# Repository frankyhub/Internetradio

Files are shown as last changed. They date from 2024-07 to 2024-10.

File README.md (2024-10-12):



<div align="center">

|[:skull:ISSUE](https://github.com/frankyhub/Internetradio/issues?q=is%3Aissue)|[:speech_balloon: Forum /Discussion](https://github.com/frankyhub/Internetradio/discussions)|[:grey_question:WiKi](https://github.com/frankyhub/Internetradio/wiki)||
|--|--|--|--|
| | | | |
||<a href="https://github.com/frankyhub/Internetradio/issues">|<a href="https://github.com/frankyhub/Internetradio/discussions">|<a href="https://github.com/frankyhub/Internetradio/releases">|
|| <a href="https://github.com/frankyhub/Internetradio/pulse" alt="Activity">| <a href="https://github.com/frankyhub/Internetradio/graphs/traffic">  |<a href="https://github.com/frankyhub?tab=stars"> |
</div>

# Internetradio
Internetradio mit WEB-Server, OTA-Funktion, TFT 1,88 oder LCD 4 Zeilen Display, digitales Amplifier Board MAX98357A

## Story
Das Internetradio steht mit einem  TFT 1,88" Display oder einem LCD 4x20 Display mit I2C Schnittstelle zur Verfügung.
Neben dem gerade gespielten Sender werden Datum und Uhrzeit, sowie die aktuelle Lautstärke angezeigt. 
In den beiden unteren Zeilen sind die Informationen zum laufenden Programm, die mit dem Audiostream mitgeschickt werden. 
Die Lautstärkeregelung erfolgt ebenso wie die Senderwahl über einen Rotary-Encoder. Die Konfiguration kann
auch über einen Browser erfolgen. Über diesen Weg ist die Senderliste veränder- und erweiterbar. 
Da nicht jede Sender-URL abspielbar ist, kann die URL über die Browserkonfiguration vor dem speichern vorab getestet werden. 

Internetradio 

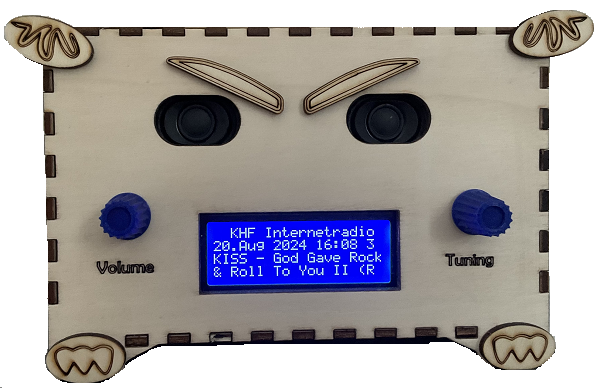
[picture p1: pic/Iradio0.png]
 

---

## Hardware

| Anzahl | Bezeichnung | 
| --- | --- |
| 1  | ESP32vn IoT UNO |
| 1  |  Shield  |
|  2 |  I2S Digitalverstärker mit MAX98357A  |
| 2  |  Lautsprecher  |
| 1  |  Widerstand 470 kOhm  |
| 1  |  Widerstand 10 kOhm  |
| 1  |  Elko 1000uF / 10V  |
| 2  | Drehgeber Encoder  |
| 2  | Drehknöpfe für 6mm Achse |
|  1 | TFT 1,88" |
|  1 | altern. LCD 4x20 |
| 1  | Gehäuse |
|  1 |  5V-Netzteil  |
| | Kabel |
|  --- |  ---  |

---

## Verdrahtung

Mit LCD-Display

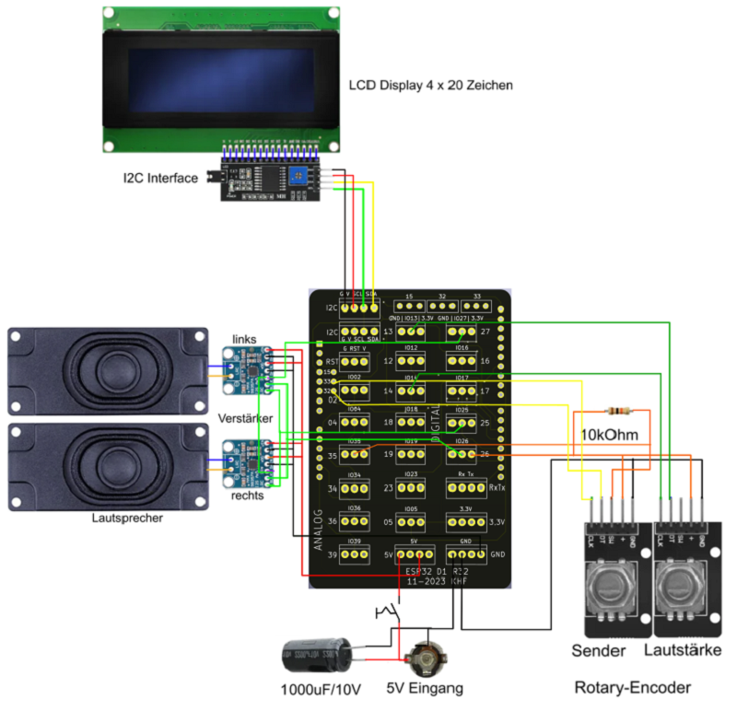
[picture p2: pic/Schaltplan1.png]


Mit TFT-Display

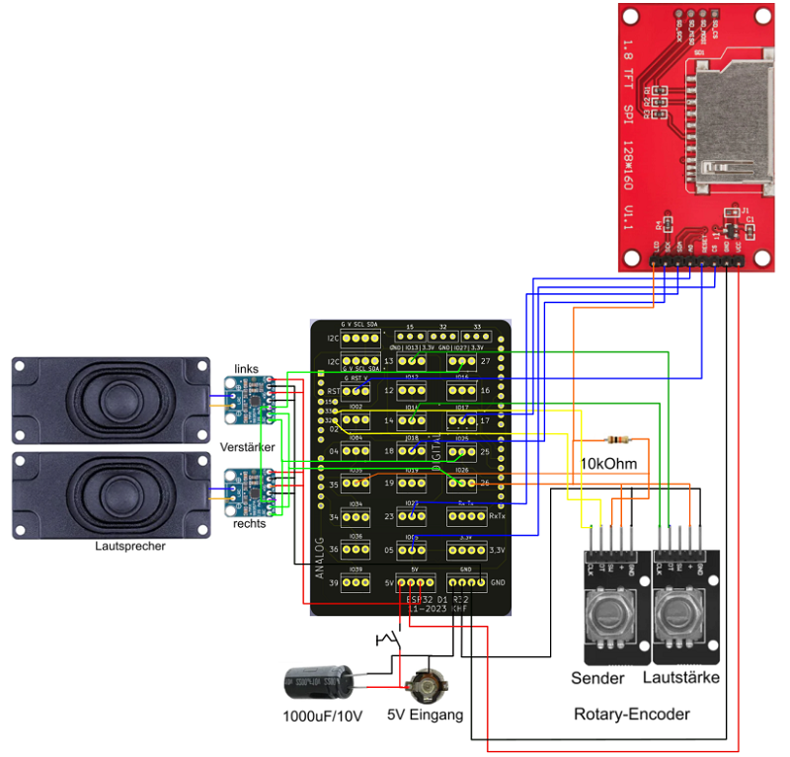
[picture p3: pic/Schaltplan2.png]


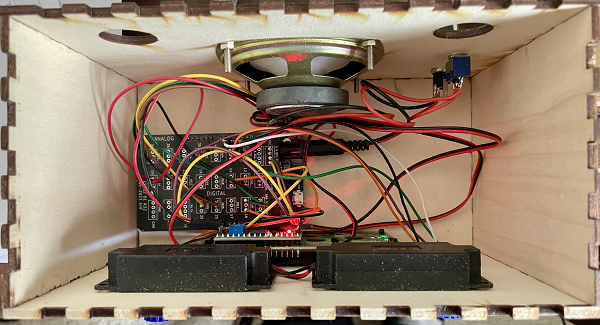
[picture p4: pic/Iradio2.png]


---

### Inbetriebnahme

Bei der ersten Inbetriebnahme ist noch keine SSID und kein WLAN-Passwort vorhanden. Es kann daher keine Verbindung zum lokalen WLAN hergestellt werden. 
Ein Accesspoint mit der SSID „Internetradio“ wird gestartet. Mit einem Smartphone oder einem Tablet kann nun eine Verbindung zu diesem 
Accesspoint hergestellt werden. Danach kann in einem Browser über die Adresse 192.168.4.1 die Konfigurationsseite aufgerufen werden.

Nach dem Neustart sollte die Verbindung zum lokalen WLAN erfolgreich hergestellt werden können. 
Die Wiedergabe der ersten Station aus der Senderliste sollte mit einer Lautstärke von 50% starten. 
Mit dem Encoder für die Lautstärke kann die Verstärkung eingestellt werden. Änderungen werden in den Präferenzen gespeichert, 
sodass beim nächsten Einschalten dieselbe Lautstärke eingestellt wird. Mit dem anderen Encoder kann ein Sender aus der Senderliste gewählt werden. 
Beim Drehen des Encoders wird in der zweiten Zeile des Displays der Name der Station angezeigt. 
Durch Drücken des Kopfes am Encoder wird die gerade angezeigte Station gespeichert und die Wiedergabe gestartet. 
Auch dieser Wert wird in den Präferenzen gespeichert und beim nächsten Start die zuletzt gewählte Station wiedergegeben. 
Wird der Knopf am Encoder innerhalb von 10 Sekunden nicht gedrückt, springt die Anzeige auf die aktuelle Station zurück.

## WLAN-Daten speichern

Aufruf "Internetradio" in den WLAN-Einstellungen

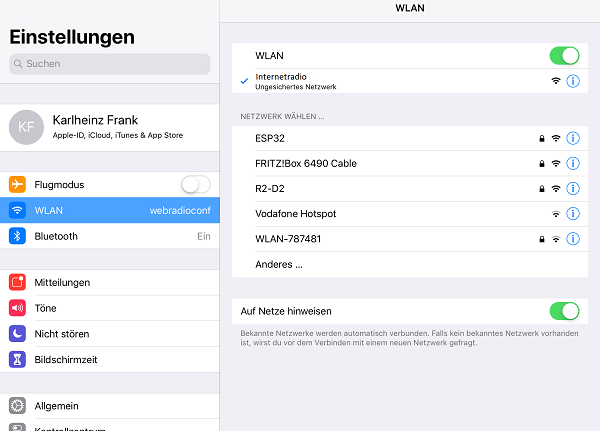
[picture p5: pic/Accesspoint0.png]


Im Browser 192.168.4.1 eingeben

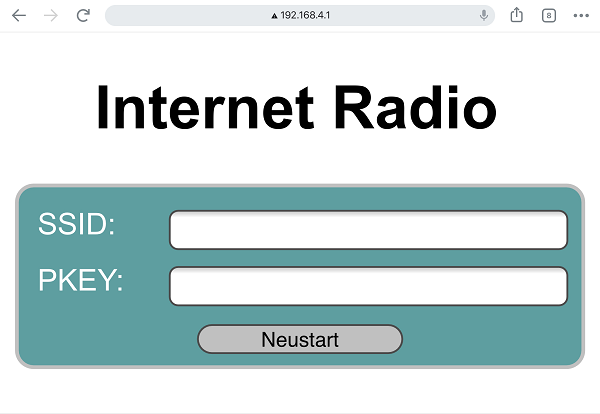
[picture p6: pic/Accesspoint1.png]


Im Browser die Zugangsdaten eingeben und neu starten

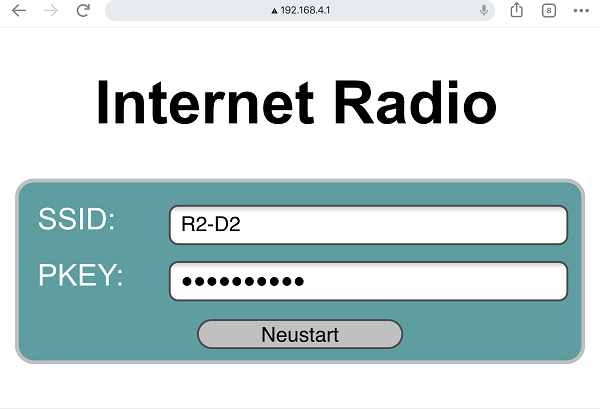
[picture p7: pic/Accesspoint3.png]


Kontrolle mit dem Seriellen Monitor

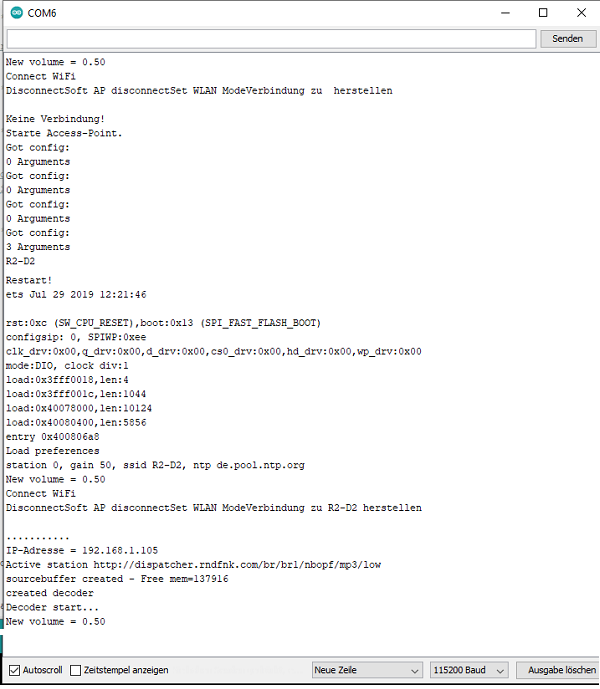
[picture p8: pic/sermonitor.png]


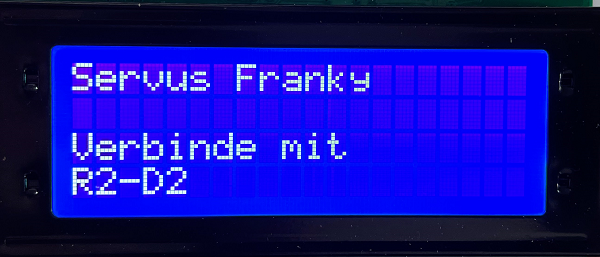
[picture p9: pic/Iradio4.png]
  

---

### Konfigurations Update

Über die URL http://Internetradio/ sollte die Konfigurationsseite abrufbar sein. Im oberen Teil können die Zugangsdaten und der NTP-Server geändert werden. 
Die Änderungen werden erst dann wirksam, wenn der Knopf „Speichern“ geklickt wurde.
Mit dem Knopf „Neustart“ kann ein Neustart ausgelöst werden.

Die Dropdown-Liste enthält alle Sender der Senderliste. Auswählbare Sender haben vor dem Namen einen schwarzen Punkt. 
Im Formular darunter sind die Daten zur ausgewählten Station gelistet und können geändert werden. 
Ist das Häkchen bei „Verwenden“ nicht gesetzt, ist die Station im Gerät nicht wählbar.
Da manche URLs nicht funktionieren, sollte man die neue URL testen (Testen-Button). 
Ein Klicken auf diesen Knopf startet die Wiedergabe der URL am Gerät. 
Sollte die Wiedergabe nicht funktionieren, wird sofort wieder auf den aktuellen Sender zurückgeschaltet und eine Meldung angezeigt. 
Ist die Wiedergabe möglich, wird eine Box mit einem Knopf angezeigt. Ein Klicken auf diesen Knopf schließt die Box und beendet den Test. 
Es wird wieder die aktuelle Station wiedergegeben.  Mit dem Knopf „Ändern“ können die Änderungen für die ausgewählte Station dauerhaft geändert werden.

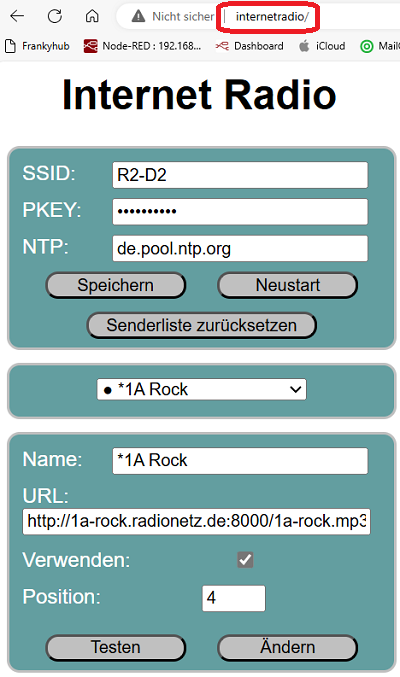
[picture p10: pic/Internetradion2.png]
 

---

 ## Programmierung über OTA

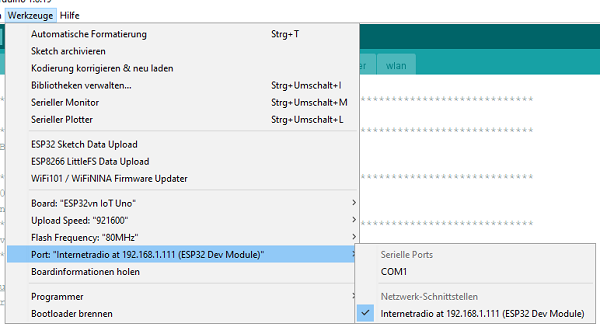
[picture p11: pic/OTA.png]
 

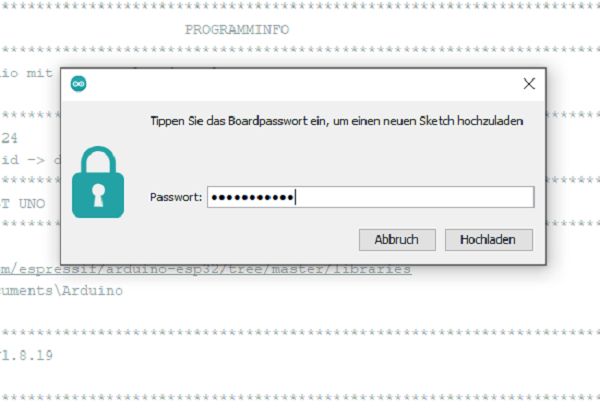
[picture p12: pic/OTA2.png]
 
 
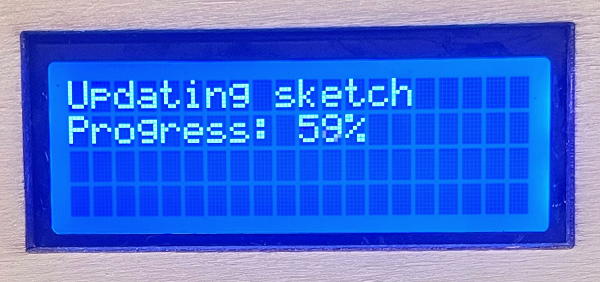
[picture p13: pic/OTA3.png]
  

 ---

## Voreingestellte Senderliste

1* Spitalradio LuZ	https://s10.streamingcloud.online:13552/radioluz320.mp3

2 Bayern1		http://dispatcher.rndfnk.com/br/br1/nbopf/mp3/low

3 Antenne Bayern	http://stream.antenne.de/antenne

4 NRW Rockradio	http://rnrw.cast.addradio.de/rnrw-0182/deinrock/low/stream.mp3

5 RT1 Rock	http://rt1.radio/tu6h1

6* 1A Rock		http://1a-rock.radionetz.de:8000/1a-rock.mp3

7* NDW		http://1a-ndw.radionetz.de/1a-ndw.mp3

8 WDR 2		http://wdr-wdr2-aachenundregion.icecastssl.wdr.de/wdr/wdr2/aachenundregion/mp3/128/stream.mp3

9 WDR3		http://wdr-wdr3-live.icecastssl.wdr.de/wdr/wdr3/live/mp3/128/stream.mp3

10 HR3		http://dispatcher.rndfnk.com/hr/hr3/suedhessen/high

11 MDR		http://mdr-284280-1.cast.mdr.de/mdr/284280/1/mp3/low/stream.mp3

12 RBB		http://dispatcher.rndfnk.com/rbb/rbb888/live/mp3/mid

13 Ant Brandenburg	http://dispatcher.rndfnk.com/rbb/antennebrandenburg/live/mp3/mid

14 N-JOY		http://icecast.ndr.de/ndr/njoy/live/mp3/128/stream.mp3

15 Radino		http://stream01.zogl.net:8906/stream

16 NRW 90er	http://rnrw.cast.addradio.de/rnrw-0182/dein90er/low/stream.mp3

17 1A Deutsche Hits http://stream.1a-webradio.de/saw-deutsch/

18 Bayern Klassik	http://dispatcher.rndfnk.com/br/brklassik/live/mp3/low

19 NRW Schlagerradio http://rnrw.cast.addradio.de/rnrw-0182/deinschlager/low/stream.mp3

20 Hörspiele	http://stream.laut.fm/hoerspiel

21 Jugend		http://stream.laut.fm/jugend_radio

22 NDR2 Niedersachsen http://icecast.ndr.de/ndr/ndr2/niedersachsen/mp3/128/stream.mp3

23 NDR1 Hannover http://icecast.ndr.de/ndr/ndr1niedersachsen/hannover/mp3/128/stream.mp3

24 WDR1 http://wdr-1live-live.icecast.wdr.de/wdr/1live/live/mp3/128/stream.mp3

25 WDR COSMO http://wdr-cosmo-live.icecast.wdr.de/wdr/cosmo/live/mp3/128/stream.mp3

26 Deutschlandfunk http://st01.sslstream.dlf.de/dlf/01/128/mp3/stream.mp3

---

<div style="position:absolute; left:2cm; ">   
<ol class="breadcrumb" style="border-top: 2px solid black;border-bottom:2px solid black; height: 45px; width: 900px;"> <p align="center"><a href="#oben">nach oben</a></p></ol>
</div>  

---

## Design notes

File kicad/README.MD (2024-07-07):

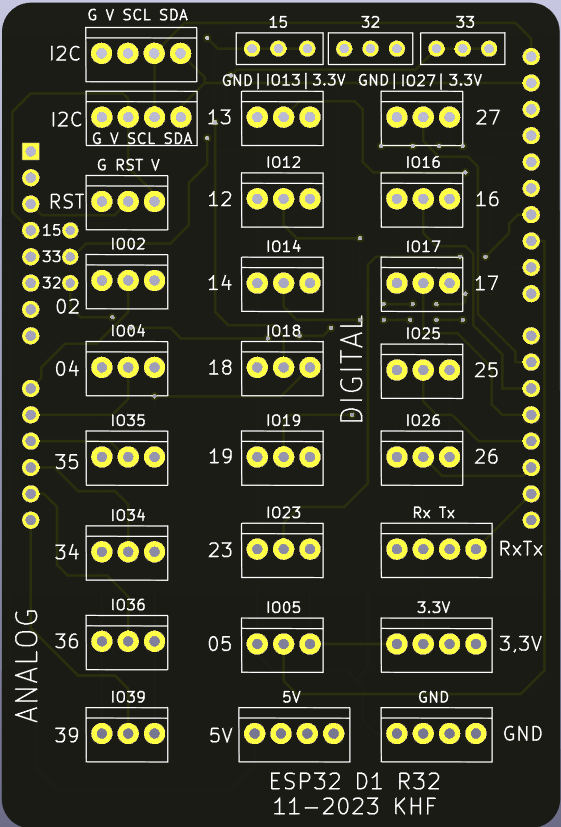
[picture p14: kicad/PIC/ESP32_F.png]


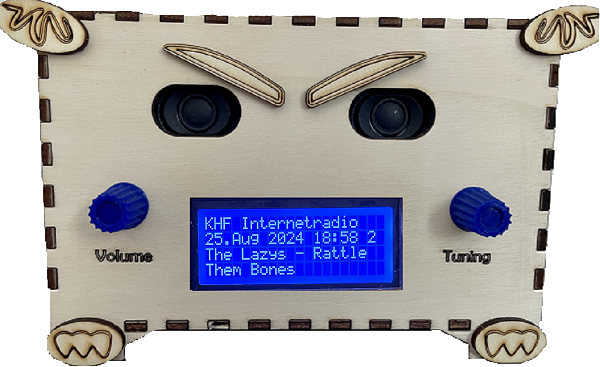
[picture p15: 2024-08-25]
pic/Iradio1.png

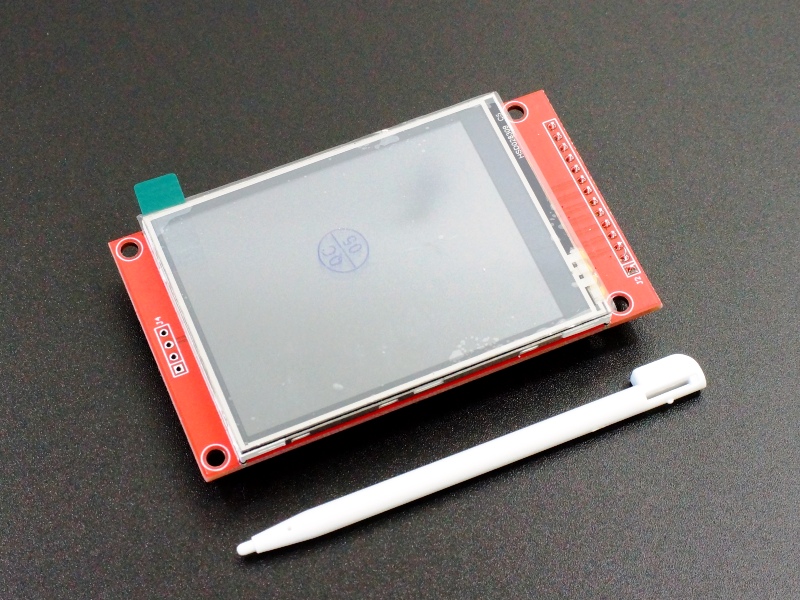
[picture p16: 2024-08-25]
pic/TFT-LCD-28-PINs.jpg

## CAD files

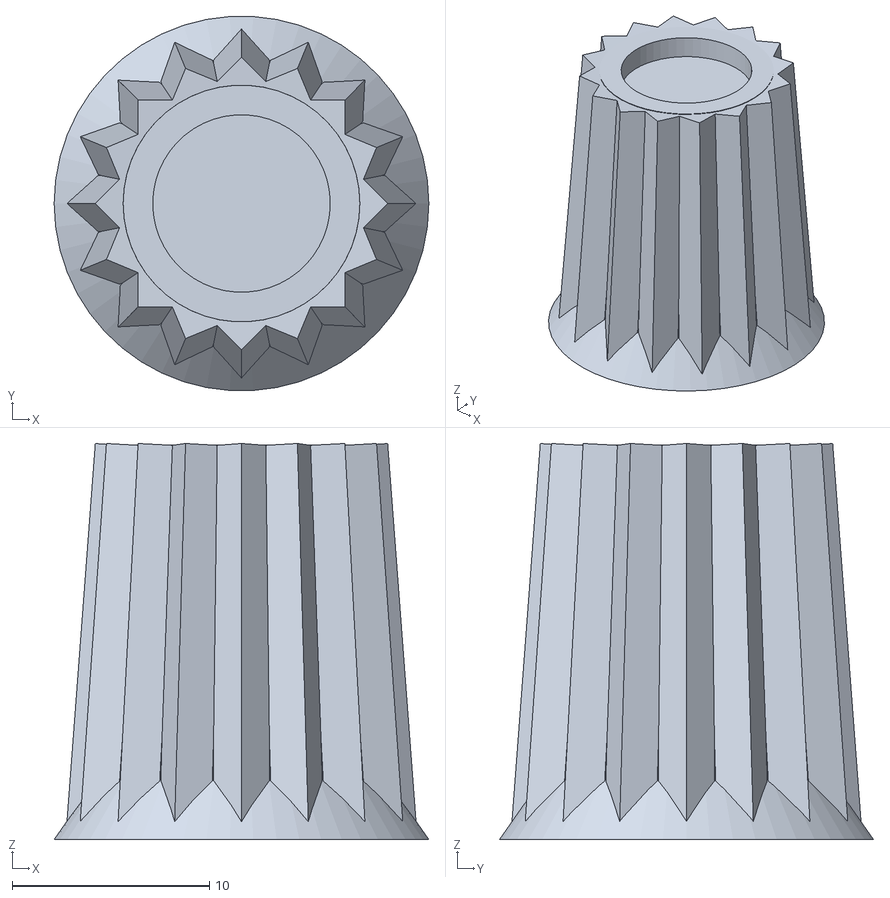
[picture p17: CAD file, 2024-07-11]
3D/Stellknopf_6-3.stl
19.0 x 19.0 x 20.1

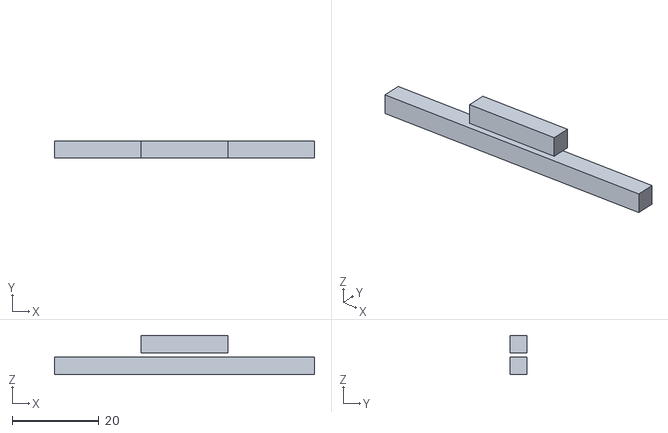
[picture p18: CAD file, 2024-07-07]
3D/LCD 4x4.stl
60.0 x 4.00 x 9.00

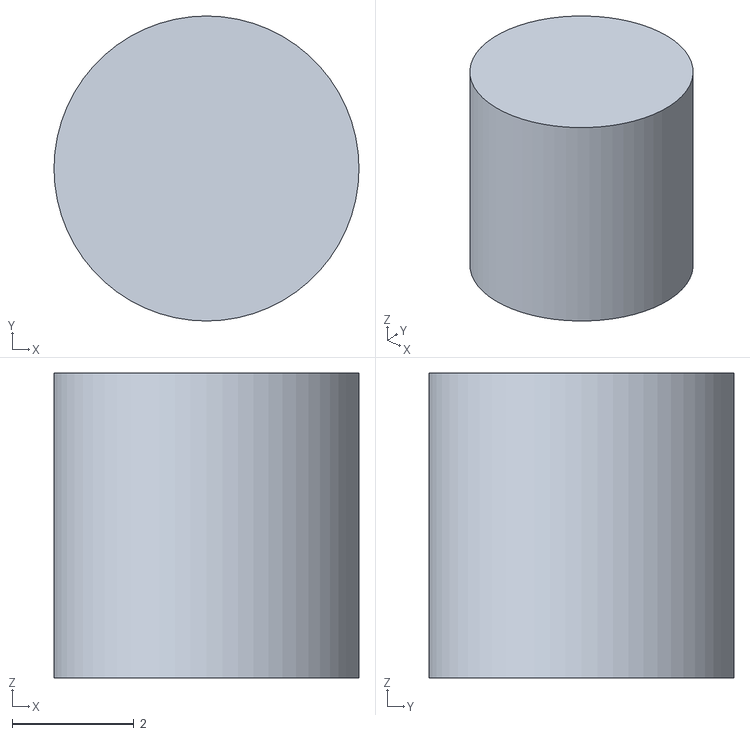
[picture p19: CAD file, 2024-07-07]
3D/Pin 5x5.stl
5.00 x 5.00 x 5.00

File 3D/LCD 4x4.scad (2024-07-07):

$fn=60;
cube(size = [60,4,4], center = true);

translate([0,5,0])
cube(size = [20,4,4], center = true);

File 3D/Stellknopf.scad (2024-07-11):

/*
*******************************************
Objekt Info: Poti Drehknopf

*******************************************
Version: 16.01.2023 khf
*******************************************
*/

//***************   Auswahl   *************
// Form der Oberseite des Knopfes.  Der Typ "Einbau" kann lackiert werden.
CapType = 1;	// [0:Flach, 1:Einbau, 2:Dome]

// Möchtest du einen großen StilZeiger?
TimerKnob=0;	// [0:Nein, 1:Ja]

// Möchtest du eine Markierung oben, um die Richtung anzuzeigen?
Pointer1 = 0;	// [0:Nein, 1:Ja]

// Möchtest du einen Richtungszeiger?
Pointer2 = 0;	// [0:Nein, 1:Ja]

// Willst du einen Rändelung um den Knopf?
Knurled = 1;	// [0:Nein, 1:Ja]

//***************   Libraries  ************

//keine

//*****************************************

//***************  Parameter   *************
$fn=80;

// Loch-Durchmesser in mm.
HoleDiameter = 6.3;

// Tiefe des Lochs im Boden (in mm). 
HoleDepth = 18;

// Wenn du ein D-förmiges Loch wünscht, stelle die Dicke auf der flachen Seite (in mm) ein.  Größere Werte für die Ebene machen das Loch kleiner.
HoleFlatThickness = 0;

// Höhe (in mm).  Wenn die Kuppelkappe ausgewählt ist, ist sie nicht in der Höhe enthalten.  Auch die Wellenlänge wird nicht gezählt.
KnobHeight = 20;

// Durchmesser des Knopfes in mm.  
KnobDiameter = 15;

// 0 = Verjüngung
TaperPercentage = 20;		// [0:0%, 10:10%, 20:20%, 30:30%, 40:40%, 50:50%]

// Breite des Rings "Dial" (in mm).  0= keine RIng
RingWidth = 2;

// Die Anzahl der Markierungen auf dem Zifferblatt.  0 = keine Markierungen   (RingWidth muss ungleich Null sein.)
RingMarkings = 0;

// Durchmesser des Lochs für die Befestigungsschraube in mm.  0 = kein Loch
ScrewHoleDiameter = 0;

//  Länge der Welle auf der Unterseite des Knopfes (in mm).  0 = keine Welle
ShaftLength = 0;

// Durchmesser der Welle auf der Unterseite des Knopfes in mm.  (ShaftLength größer Null sein.)
ShaftDiameter = 10;

// Möchtest du eine Kerbe in der Welle?  Es kann für einen Einpressknopf verwendet werden (anstelle einer Befestigungsschraube).  (ShaftLength größer Null sein.)
NotchedShaft = 0;	// [0:No, 1:Yes]


//*****************************************

//**************   Programm  **************

//////////////////////////
//Erweiterte Einstellungen
//////////////////////////

RingThickness = 5*1;
DivotDepth = 1.5*1;
MarkingWidth = 1.5*1;
DistanceBetweenKnurls = 3*1;
TimerKnobConst = 1.8*1;

//////////////////////////
//Berechnungen
//////////////////////////

PI=3.14159265*1;
KnobMajorRadius = KnobDiameter/2;
KnobMinorRadius = KnobDiameter/2 * (1 - TaperPercentage/100);
KnobRadius = KnobMinorRadius + (KnobMajorRadius-KnobMinorRadius)/2;
KnobCircumference = PI*KnobDiameter;
Knurls = round(KnobCircumference/DistanceBetweenKnurls);
Divot=CapType;

TaperAngle=asin(KnobHeight / (sqrt(pow(KnobHeight, 2) +
		pow(KnobMajorRadius-KnobMinorRadius,2)))) - 90;

DivotRadius = KnobMinorRadius*.4;

difference() {
union()
{
translate([0, 0, (ShaftLength==0)? 0 : ShaftLength-0.001])
difference()
{
union()
{
	// Primary knob cylinder
	cylinder(h=KnobHeight, r1=KnobMajorRadius, r2=KnobMinorRadius,
			$fn=50);
	
	if (Knurled)
		for (i=[0 : Knurls-1])
			rotate([0, 0, i * (360/Knurls)])
				translate([KnobRadius, 0, KnobHeight/2])
					rotate([0, TaperAngle, 0]) rotate([0, 0, 45])
						cube([2, 2, KnobHeight+.001], center=true);

 	if (RingMarkings>0)
		for (i=[0 : RingMarkings-1])
			rotate([0, 0, i * (360/RingMarkings)])
				translate([KnobMajorRadius + RingWidth/2, 0, 1])
					cube([RingWidth*.5, MarkingWidth, 2], center=true);		
	
	if (Pointer2==1)
		translate([KnobRadius, 0, KnobHeight/2-2])
			rotate([0, TaperAngle, 0])
				cube([8, 3, KnobHeight], center=true);		

	if (RingWidth>0)
		translate([0, 0, RingThickness/2])
			cylinder(r1=KnobMajorRadius + RingWidth, r2=KnobMinorRadius,
					h=RingThickness, $fn=50, center=true);

	if (Divot==2)
		translate([0, 0, KnobHeight])
			difference()
			{
				scale([1, 1, 0.5])
					sphere(r=KnobMinorRadius, $fn=50, center=true);

				translate([0, 0, 0-(KnobMinorRadius+.001)])
					cube([KnobMinorRadius*2.5, KnobMinorRadius*2.5,
							KnobMinorRadius*2], center=true);
			}

	if (TimerKnob==1) intersection()
		{
			translate([0, 0, 0-(KnobDiameter*TimerKnobConst) + KnobHeight])
			sphere(r=KnobDiameter*TimerKnobConst, $fn=80, center=true);		
	
			translate([0-(KnobDiameter*TimerKnobConst)*0.1, 0,
					KnobHeight/2])
				scale([1, 0.5, 1])
					cylinder(h=KnobHeight, r=(KnobDiameter*TimerKnobConst) *
							0.8, $fn=3, center=true);
		}
}

// Zeiger1
if (Pointer1==1)
	translate([KnobMinorRadius*.55, 0, KnobHeight + DivotRadius*.6])
		sphere(r=DivotRadius, $fn=40);

// Divot1: Zentrierter zylynischer Divot
if (Divot==1)
	translate([0, 0, KnobHeight])
		cylinder(h=DivotDepth*2, r=KnobMinorRadius-1.5, $fn=50,
				center=true);

if (ShaftLength==0)
{
	// Loch für die Welle
	translate([0, 0, HoleDepth/2 - 0.001])
		difference()
		{
			cylinder(r=HoleDiameter/2, h=HoleDepth, $fn=20,
					center=true);
	
			// D-förmiges Loch
			translate([(0-HoleDiameter)+HoleFlatThickness, 0, 0])
				cube([HoleDiameter, HoleDiameter, HoleDepth+.001],
						center=true);
		}
	
	// Loch für die Befestigungsschraube
	if (ScrewHoleDiameter>0)
		translate([0 - (KnobMajorRadius+RingWidth+1)/2, 0,
				HoleDepth/2])
			rotate([0, 90, 0])
			cylinder(h=(KnobMajorRadius+RingWidth+1),
					r=ScrewHoleDiameter/2, $fn=20, center=true);
}

// Stelle sicher, dass die unteren Enden bei z=0 sind
translate([0, 0, -10])
	cube([(KnobMajorRadius+RingWidth) * 3,
			(KnobMajorRadius+RingWidth) * 3, 20], center=true);
}

if (ShaftLength>0)
	difference()
	{
		translate([0, 0, ShaftLength/2])
			cylinder(h=ShaftLength, r=ShaftDiameter/2, $fn=20,
					center=true);

		if (NotchedShaft==1)
		{
			cube([HoleDiameter/2, ShaftDiameter*2, ShaftLength],
					center=true);
		}

		// Loch für die Welle
		translate([0, 0, HoleDepth/2 - 0.001])
			difference()
			{
				cylinder(r=HoleDiameter/2, h=HoleDepth, $fn=20,
						center=true);
		
				// D-förmiges Loch
				translate([(0-HoleDiameter)+HoleFlatThickness, 0, 0])
					cube([HoleDiameter, HoleDiameter, HoleDepth+.001],
							center=true);
			}
		
		// Loch für die Befestigungsschraube
		if (ScrewHoleDiameter>0)
			translate([0 - (KnobMajorRadius+RingWidth+1)/2, 0,
					HoleDepth/2])
				rotate([0, 90, 0])
				cylinder(h=(KnobMajorRadius+RingWidth+1),
						r=ScrewHoleDiameter/2, $fn=20, center=true);
	}
}


translate(v = [0, 0, 1]) { 
cylinder(h = 5, r1 = 6, r2 = 6, center = true);
}
translate(v = [0, 0, 4]) { 
cylinder(h = 6, r1 = 3, r2 = 3, center = true);
    }
}

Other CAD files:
3D/Stellknopf_6-2.stl
3D/Stellknopf.stl
3D/Stellknopf_6-1.stl
3D/Pin 5x5.scad

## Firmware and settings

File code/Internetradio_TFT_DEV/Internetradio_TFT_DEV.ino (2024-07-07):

/*************************************************************************************************
                                      PROGRAMMINFO
**************************************************************************************************
Funktion: WEB-Radio mit TFT 1.8 inch Spi TFT Display 128 x 160 pixels

**************************************************************************************************
Version: 06.07.2024
**************************************************************************************************
Board: ESP32vn IoT UNO
**************************************************************************************************
Libraries:
https://github.com/espressif/arduino-esp32/tree/master/libraries
C:\Users\User\Documents\Arduino
D:\gittemp\Arduino II\A156_Wetterdaten_V3
"U8g2" von Oliver in der Version 2.27.6 (2.28.10) //  U8g2 font list: https://github.com/olikraus/u8g2/wiki/fntlistall
                                                  //  U8g2 Unifont list: https://github.com/olikraus/u8g2/wiki/fntgrpunifont
"GFX Library for Arduino" von Moon On Our Nation in Version 1.3.1 //  https://github.com/moononournation/Arduino_GFX
**************************************************************************************************
C++ Arduino IDE V1.8.19

**************************************************************************************************
Einstellungen:
https://dl.espressif.com/dl/package_esp32_index.json
http://dan.drown.org/stm32duino/package_STM32duino_index.json
http://arduino.esp8266.com/stable/package_esp8266com_index.json


Display Verdrahtung:
DISPLAY ESP32
VCC     +5V
GND     GND
CS      GPIO 05
RESET   EN
A0      GPIO 17
SDA     GPIO 23
SCK     GPIO 18
LED     3.3V

Gerät     Bezeichnung     ESP32

Verstärker 
links     LRC             25
          BCLK            26
          DIN             27
          GAIN            GND
          SD              +5V
          GND             GND
          VIN             +5V
Verstärker
rechts 
          LRC             25
          BCLK            26
          DIN             27
          GAIN            GND
          SD              +5V über 470kΩ
          GND             GND
          VIN             +5V
Encoder
Lautstärke
          CLK             14
          DT              13
          SW              
          +               +3.3V
          GND             GND

Encoder 
Senderwahl
          CLK             33
          DT              32
          SW              35 3.3V über10kΩ
          +               +3.3V
          GND             GND
Versorgung
          +5V             VIN
          GND             GND

          
**************************************************************************************************/


#include <WiFi.h> 
#include <ArduinoOTA.h>

//esp32 library to save preferences in flash
#include <Preferences.h>

//instance of prefernces
Preferences pref;
Preferences sender;

//structure for station list
typedef struct {
  char url[150];  //stream url
  char name[32];  //stations name
  uint8_t enabled;//flag to activate the station
} Station;

#define STATIONS 30 //number of stations in the list

//gloabal variables
Station stationlist[STATIONS];
String ssid = "";
String pkey = "";
String ntp = "de.pool.ntp.org";
boolean connected;
uint8_t curStation = 0;   //index for current selected station in stationlist
uint8_t curGain = 200;    //current loudness
uint8_t actStation = 0;   //index for current station in station list used for streaming 
uint32_t lastchange = 0;  //time of last selection change
char title[128];           //character array to hold meta data message
bool newTitle = false;
uint32_t tick = 0;        //last tick-counter value to trigger timed event
uint32_t discon = 0;      //tick-counter value to calculate disconnected time

      
//setup
void setup() {
  Serial.begin(115200);
  Serial.println("Load preferences");
  //preferences will be saved in the EPROM of the ESP32 to keep the values even 
  //if power supply will be interrupted
  //Two topics "radio" and "senderliste" are defined. We will mount both
  pref.begin("radio", false);
  sender.begin("senderlist",false);
  //get ssid and pkey, ntp-server and last gain and last station from preferences
  if (pref.isKey("ssid")) ssid = pref.getString("ssid");
  if (pref.isKey("pkey")) pkey = pref.getString("pkey");
  if (pref.isKey("ntp")) ntp = pref.getString("ntp");
  curGain = 50; //default value
  if (pref.isKey("gain")) curGain = pref.getUShort("gain");
  curStation = 0; //default value
  //set current station to saved value if available
  if (pref.isKey("station")) curStation = pref.getUShort("station");
  if (curStation >= STATIONS) curStation = 0; //check to avoid invalid station number
  actStation = curStation;   //set active station to current station 
  Serial.printf("station %i, gain %i, ssid %s, ntp %s\n", curStation, curGain, ssid.c_str(), ntp.c_str());
  //run setup functions in the sub parts
  setup_audio(); //setup audio streams
  setup_display(); //setup display interface
  setup_senderList(); //load station list from preferences
  setup_rotary(); //init rotary encoder for station selection
  setup_gain(); //init rotary encoder for gain control
  setGain(); //set the current gain
  //Try to connect WLAN show process on display 
  displayClear();
  displayMessage(0,"Connect WLAN");
  displayMessage(1,ssid);
  Serial.println("Connect WiFi");
  connected = initWiFi(ssid, pkey);
  if (connected) { //successful connection
    displayClear();
    //setup real time clock
    configTzTime("CET-1CEST,M3.5.0/03,M10.5.0/03", ntp.c_str());
    //show date and time and the name of the station
    displayDateTime();
    showStation();
    delay(500);
    // start playing audio stream from web
    if (!startUrl(String(stationlist[actStation].url))) {
      //if no success switch to station 0
      actStation = 0;
      startUrl(String(stationlist[actStation].url));
    }
  } else { //connection not successful
    displayClear();
    displayMessage(0,"Not connected");
    displayMessage(1,"SSID: webradioconf");
    displayMessage(2,"Conf: 192.168.4.1");
    //remember current tick count to allow
    //a retry after five minutes disconnected
    discon = millis();
  }
  //setup the web server and the over the air update
  setup_webserver();
  setup_ota();
  //remember the tick count for the timed event
  tick = millis();
}


void loop() {
  //Check over the air update
  ArduinoOTA.handle();
  //Check for http requests
  webserver_loop();
  if (newTitle) {
    //show the message on the display
    displayMessage2(2,title);
    newTitle = false;
  }
  //detect a disconnect
  if (connected && (WiFi.status() != WL_CONNECTED)){
    connected = false;
    //remember tick count for automatic retry
    discon = millis();
    displayClear();
    displayMessage(1,"  Connection lost!");
  }
  if (connected) {
    audio_loop();
    rotary_loop();
    gain_loop();
  }
  //timed event updatetime display every minute  
  if ((millis() - tick) > 60000) {
    if (connected) displayDateTime();
    tick = millis();
  }
  //do a restart if device was disconnected for more then 5 minutes
  if (!connected && ((millis() - discon) > 300000)) ESP.restart();
}

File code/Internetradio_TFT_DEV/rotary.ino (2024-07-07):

//library for rotary encoder
#include "AiEsp32RotaryEncoder.h"

//used pins for rotary encoder
#define ROTARY_ENCODER_A_PIN 33
#define ROTARY_ENCODER_B_PIN 32
#define ROTARY_ENCODER_BUTTON_PIN 35
#define ROTARY_ENCODER_VCC_PIN 12 /* 27 put -1 of Rotary encoder Vcc is connected directly to 3,3V; else you can use declared output pin for powering rotary encoder */
//depending on your encoder - try 1,2 or 4 to get expected behaviour
//#define ROTARY_ENCODER_STEPS 1
//#define ROTARY_ENCODER_STEPS 2
#define ROTARY_ENCODER_STEPS 4
//instance for rotary encoder
AiEsp32RotaryEncoder rotaryEncoder = AiEsp32RotaryEncoder(ROTARY_ENCODER_A_PIN, ROTARY_ENCODER_B_PIN, ROTARY_ENCODER_BUTTON_PIN, ROTARY_ENCODER_VCC_PIN, ROTARY_ENCODER_STEPS);

//handle events from rotary encoder
//called from main loop
void rotary_loop()
{
  //dont do anything unless value changed
  if (rotaryEncoder.encoderChanged())
  {
    uint16_t v = rotaryEncoder.readEncoder();
    Serial.printf("Station: %i\n",v);
    uint8_t cnt = 0; //overflow counter, prevents endless loop if no station is enabled
    while ((!stationlist[v].enabled) && (cnt < 2)){
      v++;
      if (v >= STATIONS){
        v=0;
        cnt++;
      }
    }
    //set new currtent station and show its name
    if (v < STATIONS) {
      curStation = v;
      showStation();
      lastchange = millis();
    }
  }
  //if no change happened within 10s set active station as current station
  if ((lastchange > 0) && ((millis()-lastchange) > 10000)){
    curStation = actStation;
    lastchange = 0;
    showStation();
  }
  //react on rotary encoder switch
  if (rotaryEncoder.isEncoderButtonClicked())
  {
    //set current station as active station and start streaming
    actStation = curStation;
    Serial.printf("Active station %s\n",stationlist[actStation].name);
    pref.putUShort("station",curStation);
    if (!startUrl(String(stationlist[actStation].url))) {
      //if start fails we switch back to station 0
      actStation = 0;
      startUrl(String(stationlist[actStation].url));
    }
    //call show station to display the speaker symbol
    showStation();
  }
}

//interrupt handling for rotary encoder
void IRAM_ATTR readEncoderISR()
{
  rotaryEncoder.readEncoder_ISR();
}

void setup_rotary() {
  //start rotary encoder instance
  rotaryEncoder.begin();
  rotaryEncoder.setup(readEncoderISR);
  rotaryEncoder.setBoundaries(0, STATIONS, true); //minValue, maxValue, circleValues true|false (when max go to min and vice versa)
  rotaryEncoder.disableAcceleration();
  rotaryEncoder.setEncoderValue(actStation); //preset the value to current active station

}

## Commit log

2024-07-07 V 07072024
    [LCD 4x4.scad, LCD 4x4.stl, Pin 5x5.scad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]
2024-07-10 V 10072024
    [Stellknopf_6-2.stl]
2024-07-11 V 11072024
    [Stellknopf.scad, Stellknopf_6-3.stl]
